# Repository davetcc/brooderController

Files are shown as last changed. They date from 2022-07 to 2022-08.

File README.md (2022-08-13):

## Open Brooder and Incubator

**BE AWARE THAT THIS PROJECT USES MAINS VOLATAGES, do not proceed unless you are confident to work with such voltages safely.**

This project discusses how to build a simple incubator / brooder for hatching chicks. The project was initially a bit rushed as the chicks outgrew a tiny egg incubator very quickly, so I had to generate this in a few days. Given the situation, it turned out pretty well.

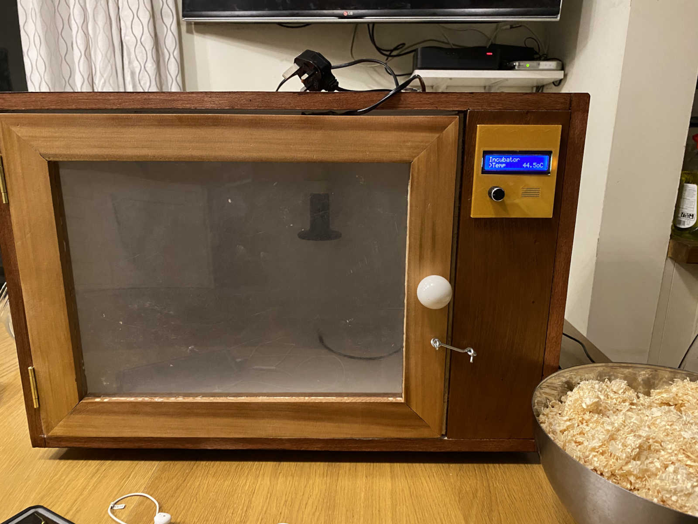
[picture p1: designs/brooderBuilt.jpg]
The brooder house built


This project uses TcMenu and for me, it runs on a spare Uno I had hanging around. Why Uno, I want to keep Uno around in my libraries for as long as possible and this provides the ultimiate requirement to keep it going. Use a display directly wired to the Uno, the wiring is discussed in the menuProject. But it is essentially an Uno directly connected, a rotary encoder directly connected, and heater, fan, and temperature on Uno pins. There is also a power off sensor attached too that saves the menu structure before power is lost.

The project is split into three sections:

* brooderCircuit - contains the schematics
* designs - contain a few paper based and tinkercad designs for the vero / patch board layout I used
* menuProject - contains a tcMenu based sketch that builds in platformIO.

In terms of wood working, the main cabinet is made out of regular WPB plywood, stained to the outside, painted white to the inside. The door is made from solid cedar wood, and the wooden part of the control panel was made from an offcut of solid 19mm oak. In terms of sizes you can work with whatever suits your situation, I went with approximately 400mm deep, 650mm wide, and approx 430mm high.

## Insulation 

Obviously there's a heater in this design, so it is best to insulate the unit at least to some extent to save energy. I am trying boards I found a craft shop that are foam in the middle with a gloss layer to the outside, these foam boards seem quite good at insulating. Here's a photo:

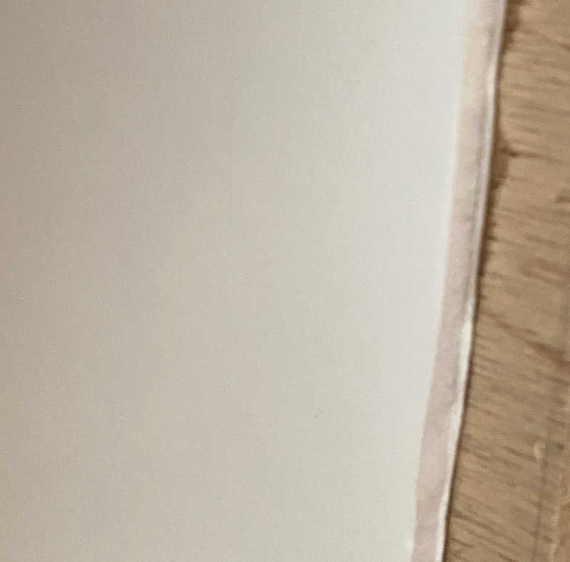
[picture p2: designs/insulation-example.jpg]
Foam board insulation


## Power supply entry

This device runs on 240V mains, it is absolutely essential that the power entry is safely managed, with an appropriate fuse and switch. I used an all in one unit, along with the panel that is in the designs/power directory, it is a free cad design. Again, as I said earlier, this project uses mains voltages, unless you are experienced in electronics, and used to working with live AC voltages, it is better not to attempt this project.

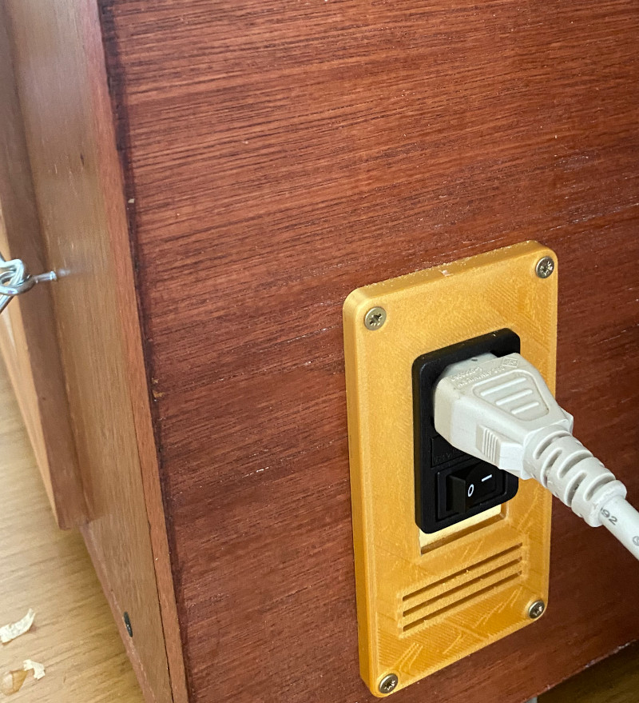
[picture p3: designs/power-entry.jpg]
Power entry panel


There's a few more images and design documents in the designs folder.

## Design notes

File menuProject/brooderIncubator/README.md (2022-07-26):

## Brooder and Incubator

This project is a control facility based around an Uno or other ATMega32x controller.

## Wiring

### Rotary encoder

All inputs

A: 2
B: A5
OK: A4

### LCD display

Standard 16x2 LCD connected directly. Backlight always on. All outputs

D0-D3: 9, 10, 11, 12 
RS: 8
EN: 7

### POWER_OFF

This is taken from the PSU and will cause an immediate write to ROM. Input

Pin: 5

### FAN Control

The fan is current boosted by a transistor, output turns on fan.

Pin: 13

### Heater control

The heater control is provided by a triac circuit with zero cross. Output turns on heater.

Pin: 7

### Speaker

The speaker is a small speaker connected to a PWM pin and pulsed.

Pin: 6

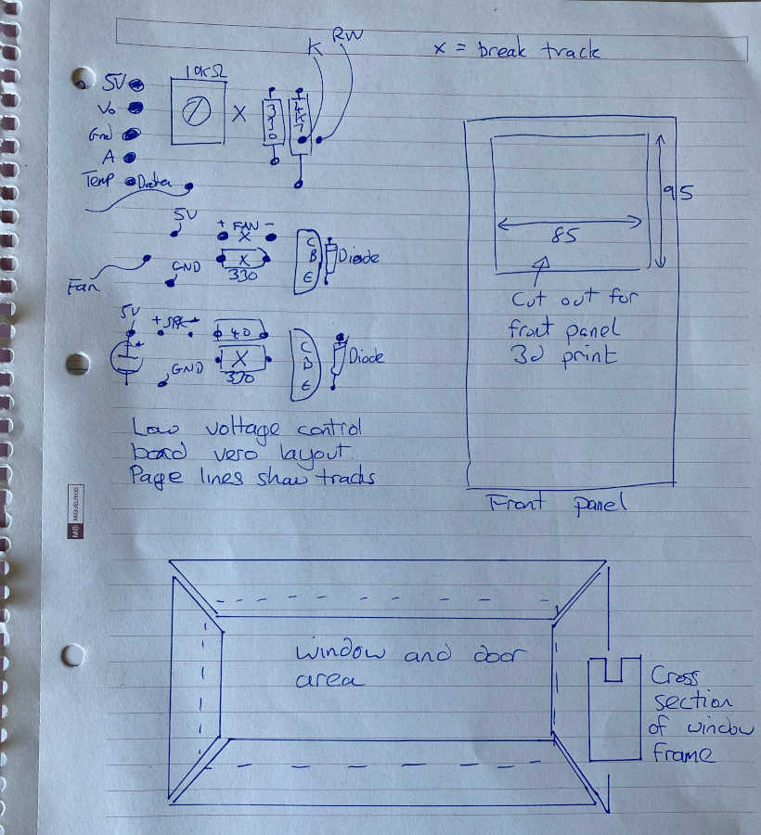
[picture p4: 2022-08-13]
designs/low-voltage-board-door-front.jpg

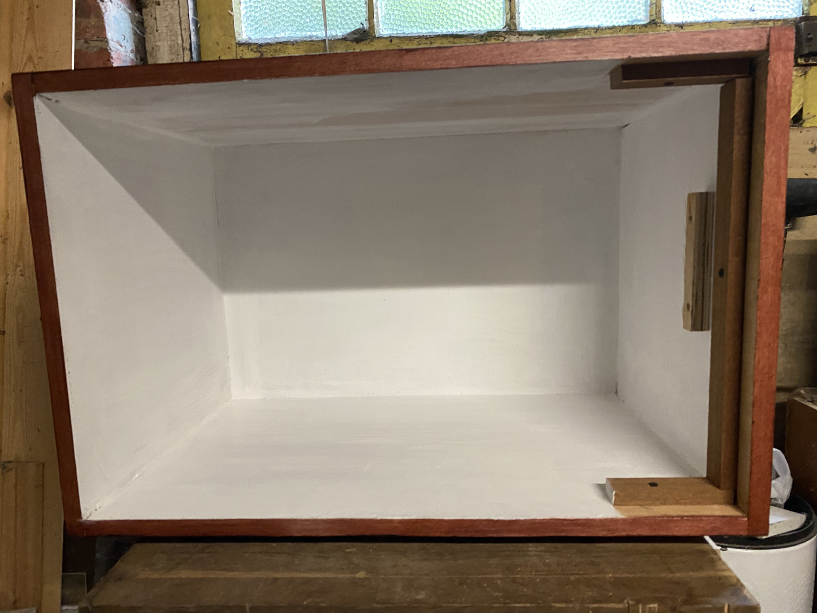
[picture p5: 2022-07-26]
designs/boxFrontAllRemoved.jpg

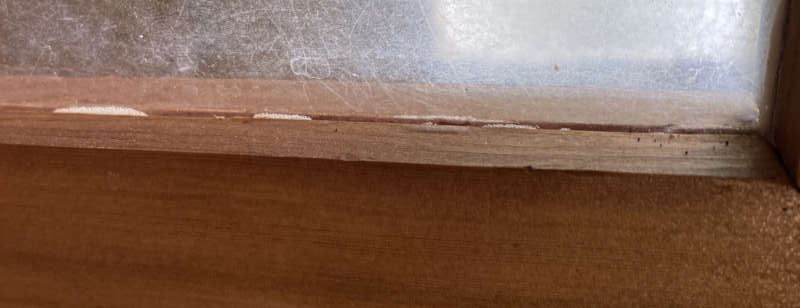
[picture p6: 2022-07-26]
designs/windowClose.jpg

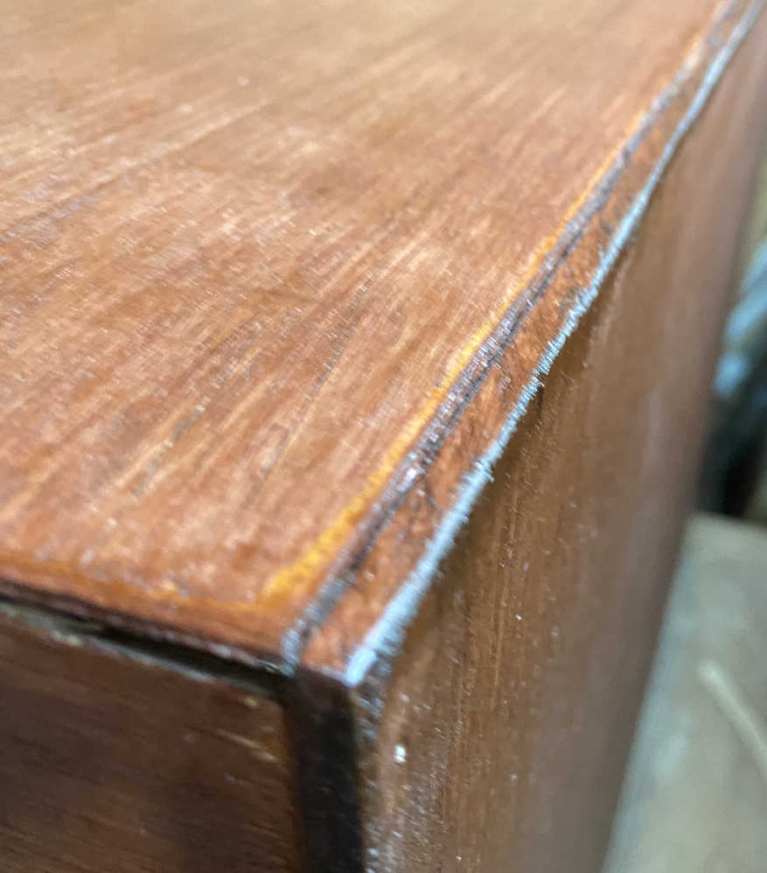
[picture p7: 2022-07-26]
designs/boxBack.jpg

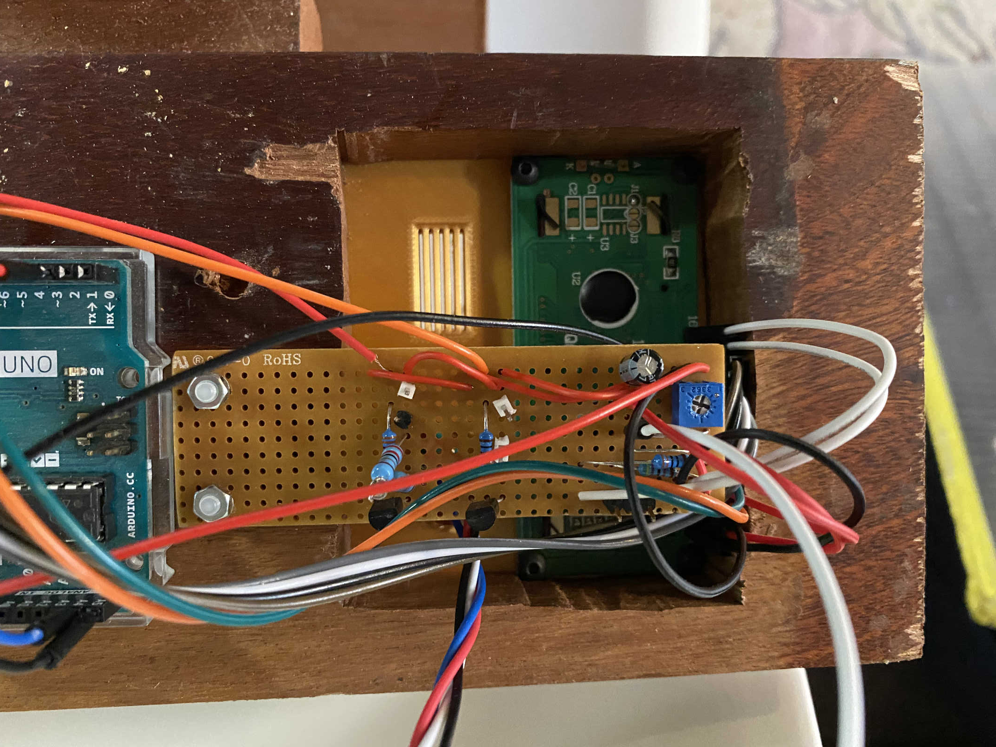
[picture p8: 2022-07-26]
designs/lowVoltageBoard.jpg

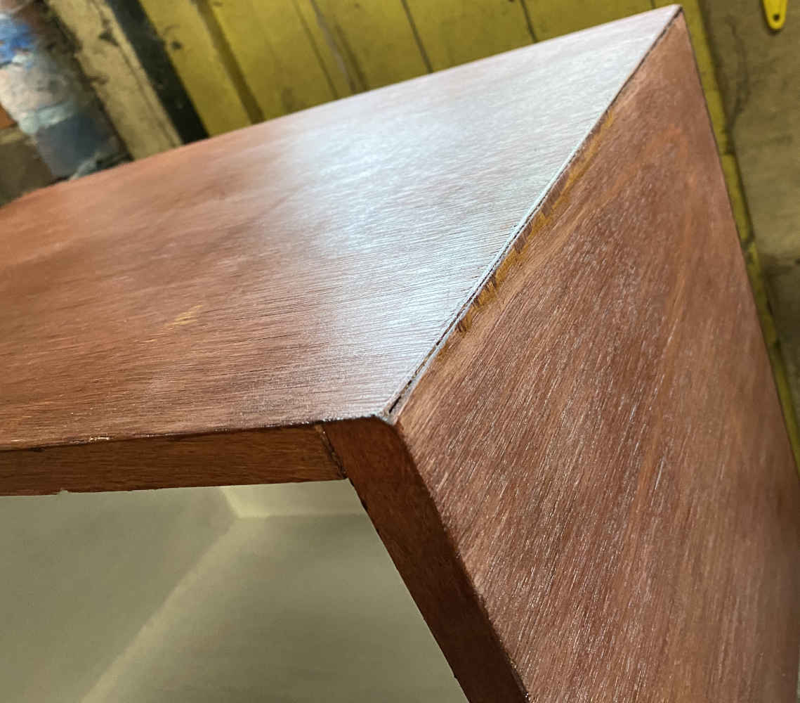
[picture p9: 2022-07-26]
designs/box_side.jpg

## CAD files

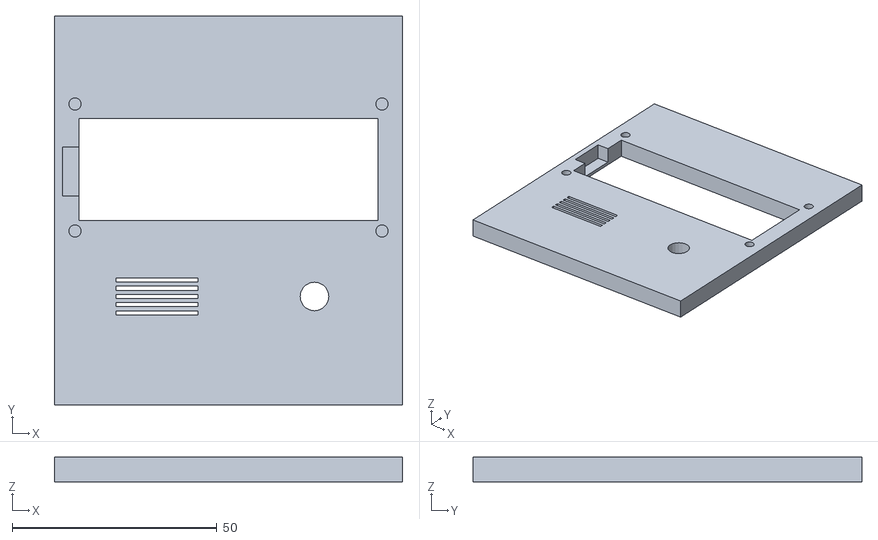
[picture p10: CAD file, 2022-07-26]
designs/FrontControlPanel.stl
85.0 x 95.0 x 6.00

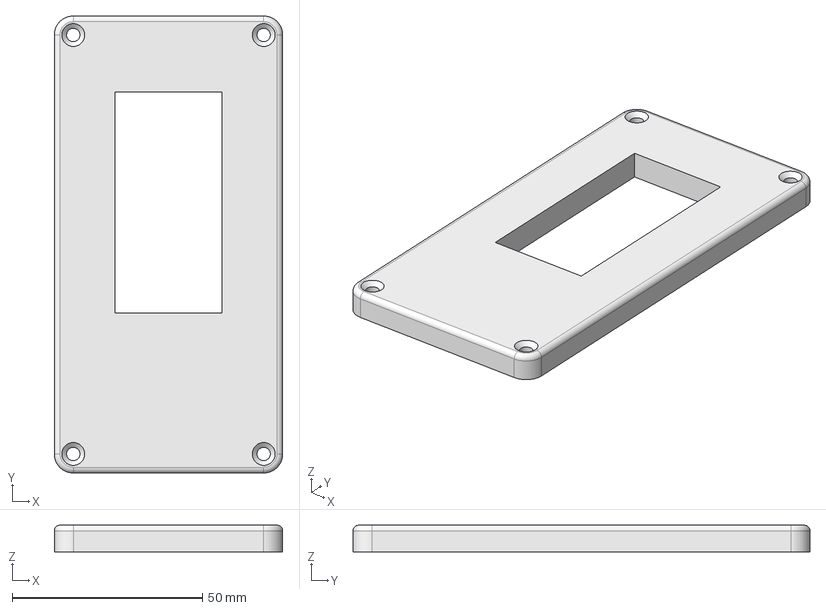
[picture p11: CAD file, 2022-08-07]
designs/power/powerEntry.FCStd
60.0 x 120.0 x 7.00 mm

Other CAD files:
designs/power/powerEntry.stl

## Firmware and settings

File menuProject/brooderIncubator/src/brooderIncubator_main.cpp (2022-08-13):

#include "brooderIncubator_menu.h"
#include "DallasTemperature.h"

#define PWR_OFF_DETECT 3
#define HEATER_PIN 13
#define SPEAKER_PIN 6
#define TEMP_DETECT_PIN 5
#define SAVE_THRESHOLD 60000

OneWire roomTempWire(TEMP_DETECT_PIN);
DallasTemperature roomTemp(&roomTempWire);
bool tempRequested = false;
int currentSpeakerValue = 0;


class SaveEvent : public BaseEvent {
private:
    unsigned long lastSaveMillis = 0;
public:
    void exec() override {
        auto millisNow = millis();
        if((millisNow - lastSaveMillis) > SAVE_THRESHOLD) {
            menuMgr.save(0xfade);
        }
    }

    uint32_t timeOfNextCheck() override {
        return secondsToMillis(1UL);
    }
} saveEvent;

void saveInterruptTriggered() {
    saveEvent.markTriggeredAndNotify();
}

void setup() {
    pinMode(PWR_OFF_DETECT, INPUT);
    pinMode(HEATER_PIN, OUTPUT);
    pinMode(SPEAKER_PIN, OUTPUT);
    digitalWrite(HEATER_PIN, 0);
    digitalWrite(SPEAKER_PIN, 0);

    setupMenu();

    roomTemp.begin();
    roomTemp.setWaitForConversion(false);
    taskManager.scheduleFixedRate(500, []() {
        if(tempRequested) {
            float deg = roomTemp.getTempCByIndex(0);
            if(deg > 0.0F) {
                tempRequested = false;

                auto allowableError = menuSettingsAccuracy.getAsFloatingPointValue();
                auto tempUser = menuSettingsReqdTemp.getAsFloatingPointValue();
                bool lampNeeded = menuHeatLamp.getBoolean() ? (deg < (tempUser)) : deg < (tempUser - allowableError);
                menuHeatLamp.setBoolean(lampNeeded);
                digitalWrite(HEATER_PIN, lampNeeded);
                menuTemp.setFromFloatingPointValue(deg);

                auto unacceptableError = allowableError + 1.5F;
                bool buzzerRequired = deg > (tempUser + unacceptableError) || deg < (tempUser - unacceptableError);
                menuBuzzer.setBoolean(buzzerRequired);
                if(buzzerRequired && menuSettingsEnableBuzzer.getBoolean()) {
                    currentSpeakerValue = currentSpeakerValue == 128 ? 85 : currentSpeakerValue == 85 ? 0 : 128;
                    analogWrite(SPEAKER_PIN, currentSpeakerValue);
                } else {
                    analogWrite(SPEAKER_PIN, 0);
                }

                return;
            }
        }
        roomTemp.requestTemperatures();
        tempRequested = true;

    });
    
    menuMgr.load(0xfade, []() {
        menuSettingsAccuracy.setCurrentValue(3);
        menuSettingsReqdTemp.setCurrentValue(62);
    });

    attachInterrupt(PWR_OFF_DETECT, saveInterruptTriggered, CHANGE);

    taskManager.registerEvent(&saveEvent);
}

void loop() {
    taskManager.runLoop();
}

const char pgmSettings[] PROGMEM = "Settings ";

void CALLBACK_FUNCTION onSaveSettings(int /*id*/) {
    menuMgr.save(0xfade);
    auto dlg = renderer.getDialog();
    if(dlg->isInUse()) return;
    dlg->setButtons(BTNTYPE_CLOSE, BTNTYPE_NONE);
    dlg->show(pgmSettings, false);
    dlg->copyIntoBuffer("saved");
}

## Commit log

2022-07-26 adding designs
    [FrontControlPanel.stl]
2022-07-26 add flyback diodes
    [brooder-mainboard.sch]
2022-07-29 Circuit updates
    [brooder-mainboard.sch]
2022-08-07 adding power facilities
    [brooder-mainboard.sch, powerEntry-powerPanel.stl, powerEntry.FCStd]
2022-08-13 Code updated to match pinouts on device.
